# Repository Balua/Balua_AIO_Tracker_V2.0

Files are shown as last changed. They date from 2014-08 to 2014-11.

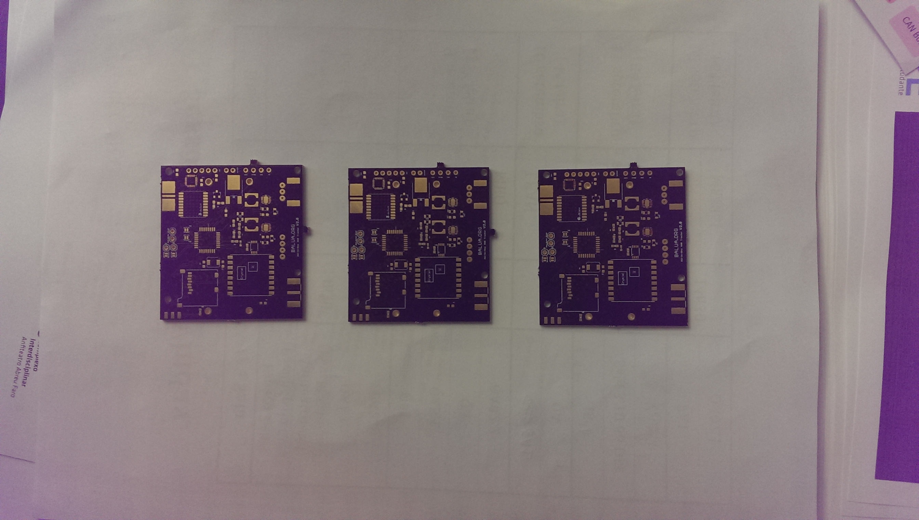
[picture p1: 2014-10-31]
PCB.jpg

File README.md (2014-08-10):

### Balua_AIO_Tracker_V2.0 - Board finished for printing, schematic and layout completed but still to be tested...

#### Updated version of the original tracker found in the Balua_AIO_Tracker_V1.0 repository with extra features and small corrections

#### Features:

#####Microprocessor
- ATMEGA 328p smd package

#####Power
- Step up Boost Converters from 2 AA Batteries to 3.3V and 5V

#####Communication
- Radiometrix HX1 - VHF Narrow Band FM High Power (300mW) Transmitter with SMA Antenna
- RFM22B ISM Transceiver Module with SMA Antenna

#####GPS
- Ublox Max 7 GPS with Quad V GPS antenna with jumpers in the RX/TX line and in the I2C for hardware selectable communication mode (NEW!!!)

#####Sensors
- SMD Onewire temperature sensor - DS18B20
- Battery Voltage sensing
- 0-15psi Pressure Sensor SMT mount - HSCSANN015PA2A3
- 9-axis Motion Tracking MEMS (3-axis gyroscope, 3-axis accelerometer and magnetometer) - MPU-9150 (NEW!!!)

#####Storage
- MicroSD Socket

#####Programming
- SMD AVR SPI Programming pins available (NEW!!!)

#####External pins
- I2c Pins with pull-up for expansion available
- 2 pins for Software Serial
- 2 pins for Hardware Serial
- Power Pins for external power (VBatt, 5V, 3.3V and GND) (NEW!!!)
- Power pins for Cutoff system (NEW!!!)

#####Other
- On Board AA battery holder
- 5V boost converter with enable controllable
- UBlox GPS Power ON Controllable
- RFM22B Radio enable pin Controllable
- On board LED
- Cutoff System implemented (NEW!!!)

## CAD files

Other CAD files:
AIO_tracker_V1.0-tcream.dxf
AIO_tracker_V1.0-bcream.dxf

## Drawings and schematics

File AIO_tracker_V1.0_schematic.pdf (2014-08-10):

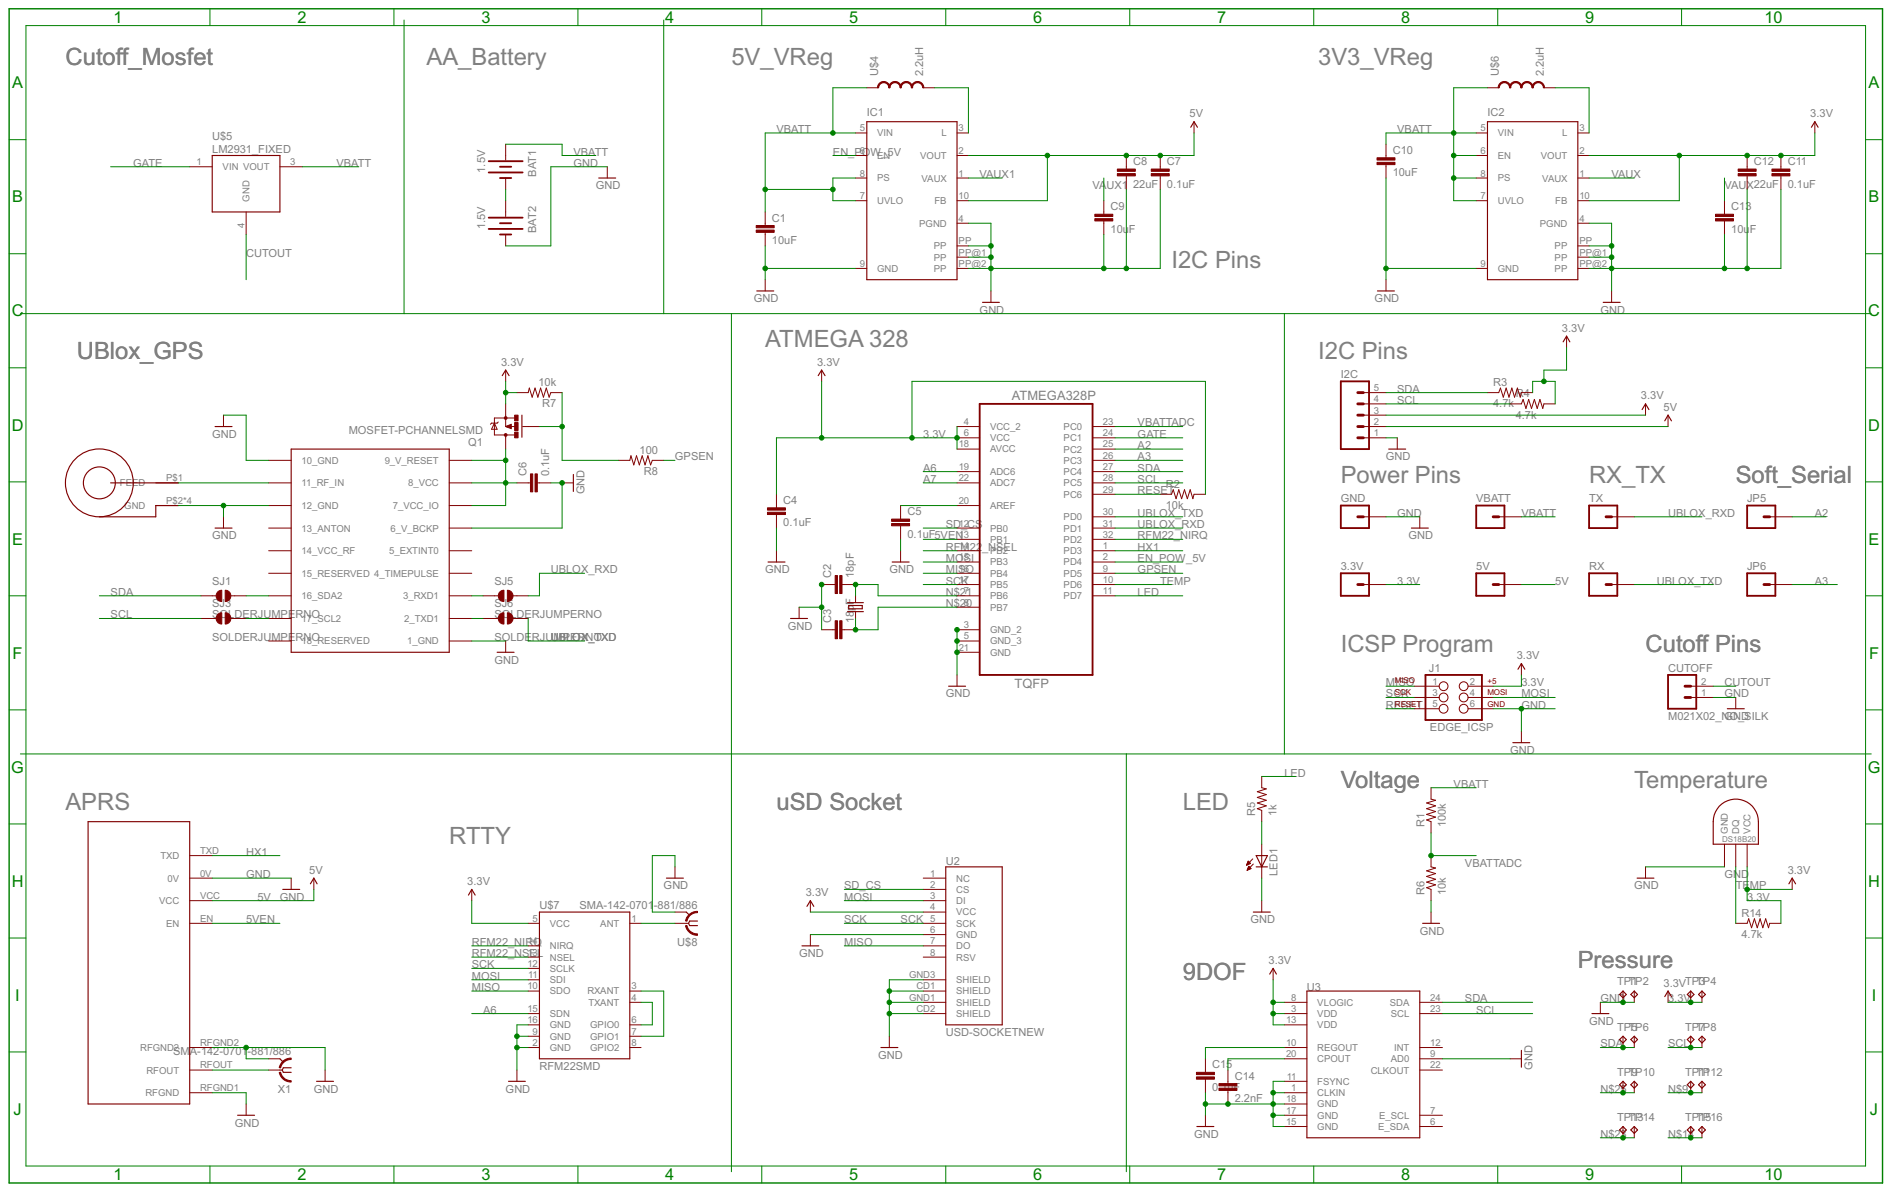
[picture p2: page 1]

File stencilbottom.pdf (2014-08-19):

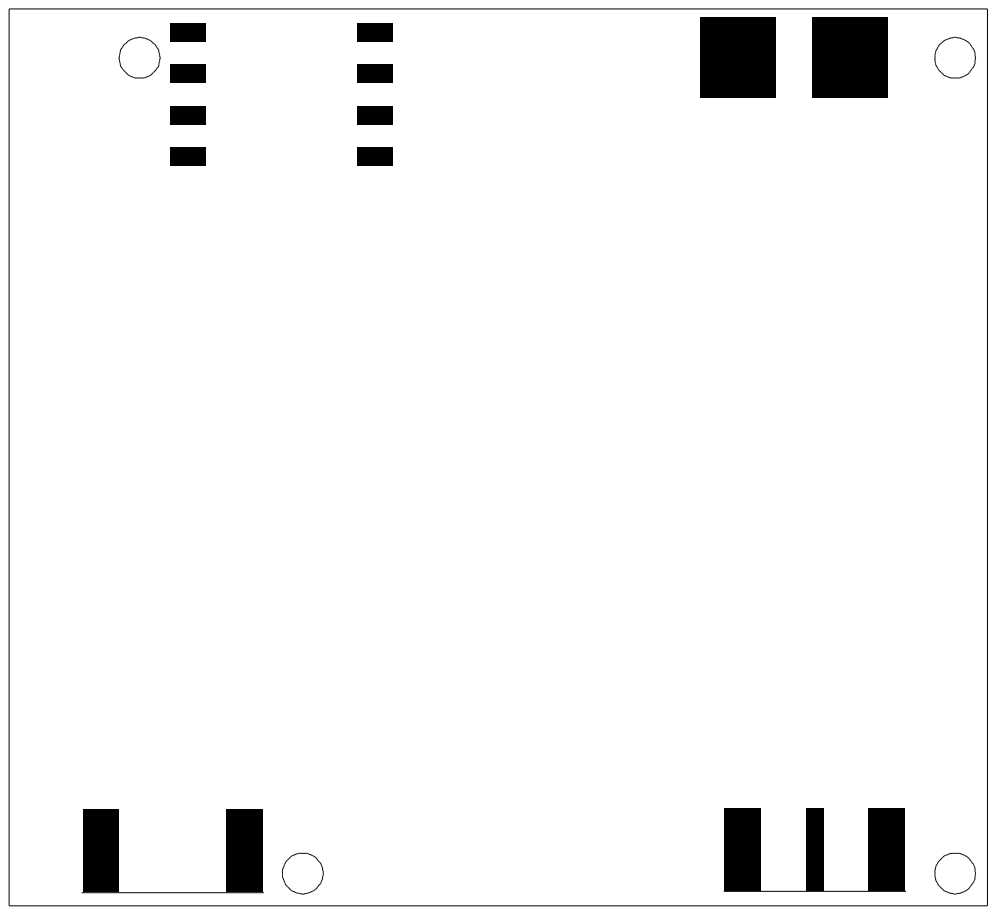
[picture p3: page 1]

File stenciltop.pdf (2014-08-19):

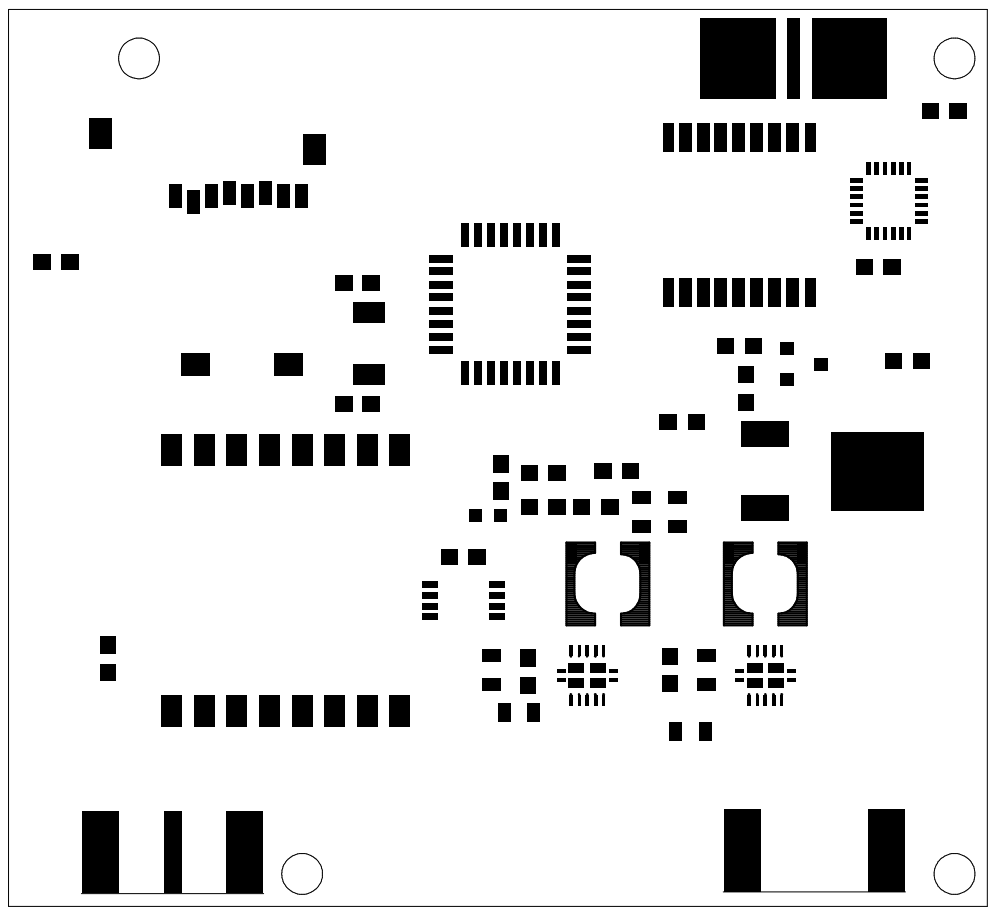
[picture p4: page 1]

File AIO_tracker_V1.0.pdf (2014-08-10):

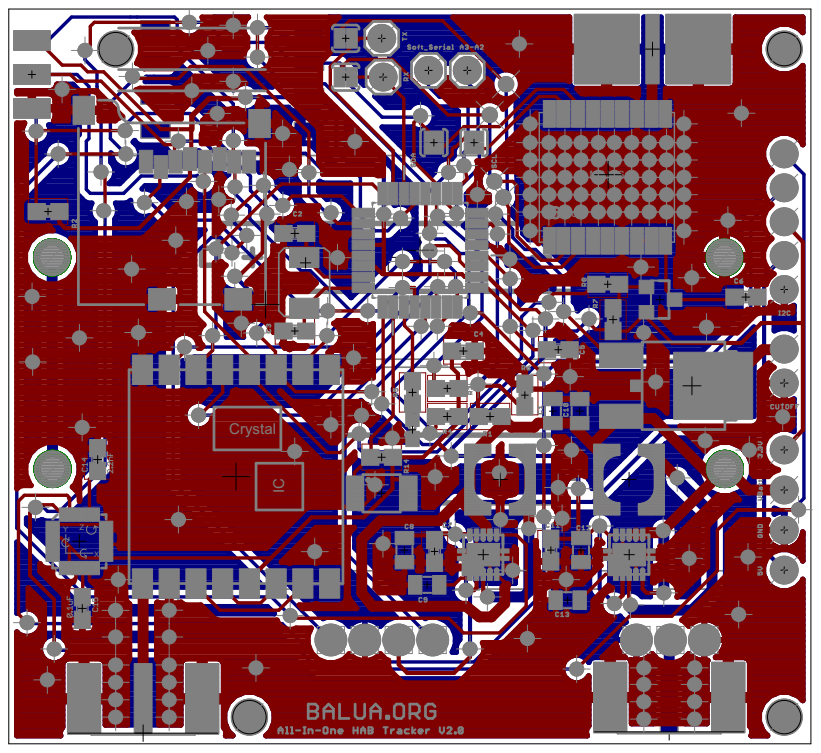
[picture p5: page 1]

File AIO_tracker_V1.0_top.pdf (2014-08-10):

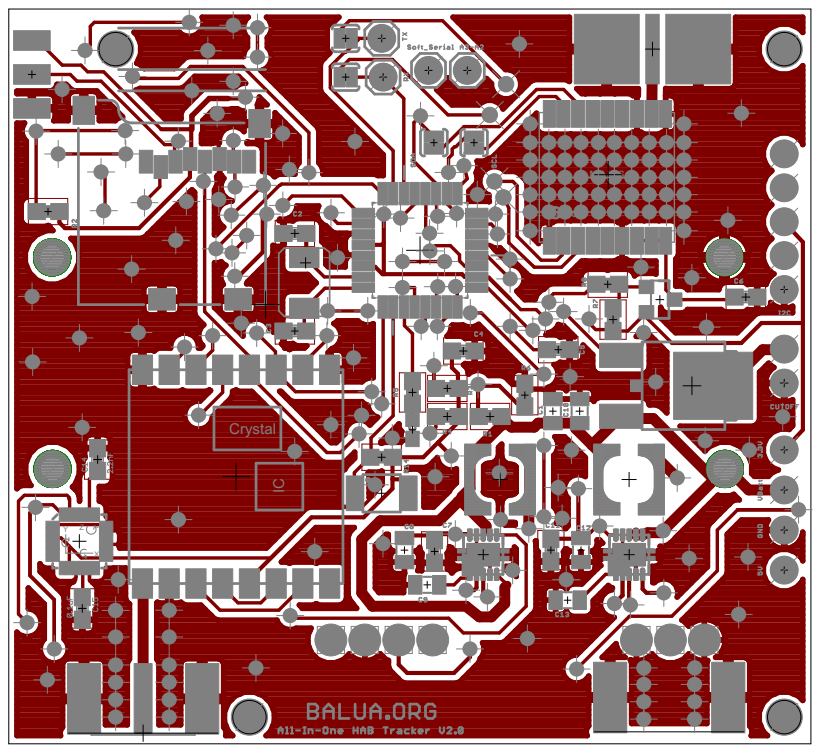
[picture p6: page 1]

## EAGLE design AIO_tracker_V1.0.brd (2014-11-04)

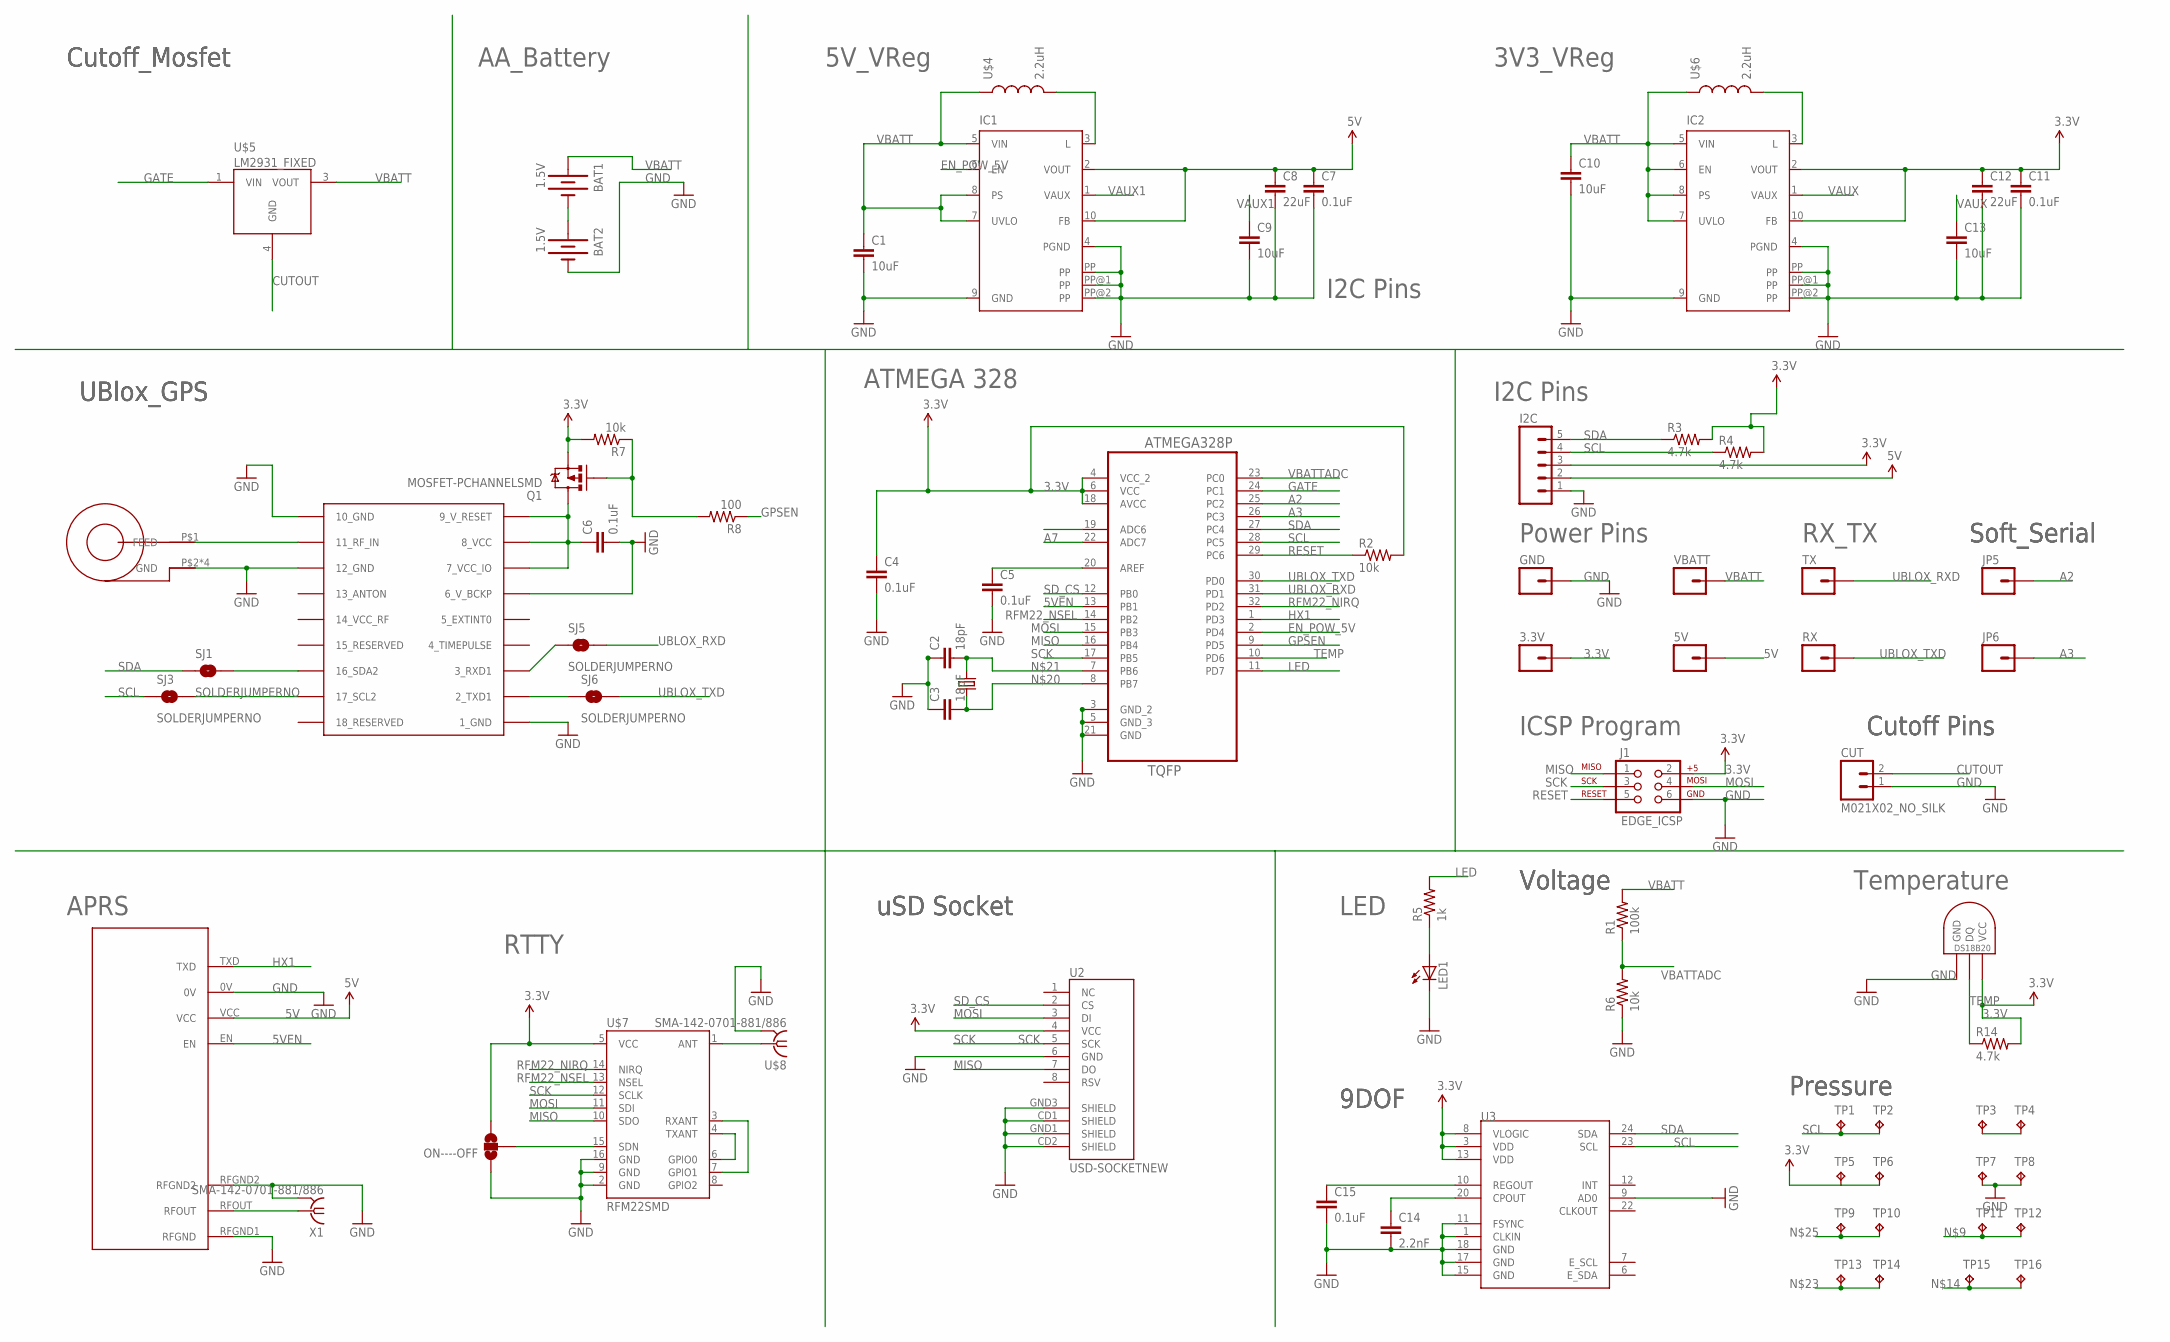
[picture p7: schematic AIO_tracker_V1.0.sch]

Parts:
3.3V, 5V: M01SMDNS; 1X01NS
BAT1, BAT2: 1.5V; BATTERY-AA-KIT
C1, C9, C10, C13: 10uF; 0805
C2, C3: 18pF; 0603-CAP
C4, C5, C6, C7, C11, C15: 0.1uF; 0603-CAP
C8, C12: 22uF; 0805
C14: 2.2nF; 0603-CAP
CUT: M021X02_NO_SILK; 1X02_NO_SILK
GND: M01SMDNS; 1X01NS
I2C: M05NO_SILK; 1X05_NO_SILK
IC1, IC2: TPS61201; S-PDSO-N10
J1: EDGE_ICSP; EDGE_MOUNTED_ICSP
JP5, JP6: M01PTH; 1X01
LED1: LED0603; LED-0603
ON----OFF: SOLDERJUMPER_2WAY-OLDT; SJ_2
Q1: MOSFET-PCHANNELSMD; SOT23-3
R1: 100k; 0603-RES
R2, R6, R7: 10k; 0603-RES
R3, R4, R14: 4.7k; 0603-RES
R5: 1k; 0603-RES
R8: 100; 0603-RES
RX: M01PTH; 1X01
SJ1, SJ3, SJ5, SJ6: SOLDERJUMPERNO; SJ_2S-NO
TP1, TP2, TP3, TP4, TP5, TP6, TP7, TP8, TP9, TP10, TP11, TP12, TP13, TP14, TP15, TP16: TPTP10SQ; TP10SQ
TX: M01PTH; 1X01
U1: ATMEGA328P-AU; QFP80P900X900X120-32N
U2: USD-SOCKETNEW; MICRO-SD-SOCKET-PP
U3: MPU-9150QFN-24-NP; QFN-24-NP
U$1: UBLOX_MAX
U$2: JDGA-REMQV-ANTENNA; JDGA-RIGID_COMBO_PAD
U$3: NTX2-VERTICAL
U$4, U$6: 2.2uH; COILCRAFT_MSS5131
U$5: LM2931_FIXED; DPAK
U$7: RFM22SMD; RFM22-XXX-S2
U$8: SMA-142-0701-881/886; J502-ND-142-0701-881/886
U$9: DS1820; µSOP8
VBATT: M01SMDNS; 1X01NS
X1: SMA-142-0701-881/886; J502-ND-142-0701-881/886
Y1: ABRACON_ABM3_CRYSTAL

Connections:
3.3V: 3.3V.1, C4.1, C11.1, C12.1, I2C.3, IC2.2 (VOUT), IC2.10 (FB), J1.2, ON----OFF.3, Q1.2 (S), R2.2, R3.2, R4.2, R7.2, R14.2, TP5.TP, TP6.TP, U1.4 (VCC_2), U1.6 (VCC), U1.18 (AVCC), U2.4 (VCC), U3.3 (VDD), U3.8 (VLOGIC), U3.13 (VDD), U$7.5 (VCC), U$9.8 (VCC)
5V: 5V.1, C7.1, C8.1, I2C.2, IC1.2 (VOUT), IC1.10 (FB), U$3.VCC
5VEN: U1.13 (PB1), U$3.EN
A2: JP5.1, U1.25 (PC2)
A3: JP6.1, U1.26 (PC3)
A7: U1.22 (ADC7)
CUTOUT: CUT.2, U$5.4 (GND)
EN_POW_5V: IC1.6 (EN), U1.2 (PD4)
GATE: U1.24 (PC1), U$5.1 (VIN)
GND: BAT2.GND@1 (-), C1.2, C2.1, C3.1, C4.2, C5.2, C6.2, C7.2, C8.2, C9.2, C10.2, C11.2, C12.2, C13.2, C14.2, C15.2, CUT.1, GND.1, I2C.1, IC1.4 (PGND), IC1.9 (GND), IC1.PP, IC1.PP@1 (PP), IC1.PP@2 (PP), IC2.4 (PGND), IC2.9 (GND), IC2.PP, IC2.PP@1 (PP), IC2.PP@2 (PP), J1.6, LED1.C, ON----OFF.1, R6.1, TP7.TP, TP8.TP, U1.3 (GND_2), U1.5 (GND_3), U1.21 (GND), U2.6 (GND), U2.CD1 (SHIELD), U2.CD2 (SHIELD), U2.GND1 (SHIELD), U2.GND3 (SHIELD), U3.1 (CLKIN), U3.9 (AD0), U3.11 (FSYNC), U3.15 (GND), U3.17 (GND), U3.18 (GND), U$1.1_GND, U$1.6_V_BCKP, U$1.10_GND, U$1.12_GND, U$2.P$2 (GND), U$2.P$3 (GND), U$2.P$4 (GND), U$2.P$5 (GND), U$3.0V, U$3.RFGND1 (RFGND), U$3.RFGND2, U$7.2 (GND), U$7.9 (GND), U$7.16 (GND), U$8.G@1 (2), U$8.G@2 (2), U$8.G@3 (2), U$8.G@4 (2), U$9.4 (GND), X1.G@1 (2), X1.G@2 (2), X1.G@3 (2), X1.G@4 (2)
GPSEN: R8.1, U1.9 (PD5)
HX1: U1.1 (PD3), U$3.TXD
LED: R5.2, U1.11 (PD7)
MISO: J1.1, U1.16 (PB4), U2.7 (DO), U$7.10 (SDO)
MOSI: J1.4, U1.15 (PB3), U2.3 (DI), U$7.11 (SDI)
unnamed: LED1.A, R5.1
unnamed: Q1.1 (G), R7.1, R8.2
unnamed: U$1.11_RF_IN, U$2.P$1 (FEED)
unnamed: C5.1, U1.20 (AREF)
unnamed: U$3.RFOUT, X1.1
unnamed: C6.1, Q1.3 (D), U$1.7_VCC_IO, U$1.8_VCC, U$1.9_V_RESET
unnamed: IC1.3 (L), U$4.P$1 (2)
unnamed: TP11.TP, TP12.TP
unnamed: BAT1.GND@1 (-), BAT2.PWR@1 (+)
unnamed: SJ5.1, U$1.3_RXD1
unnamed: SJ6.1, U$1.2_TXD1
unnamed: U$7.1 (ANT), U$8.1
unnamed: TP15.TP, TP16.TP
unnamed: SJ1.2, U$1.16_SDA2
unnamed: SJ3.2, U$1.17_SCL2
unnamed: C15.1, U3.10 (REGOUT)
unnamed: C14.1, U3.20 (CPOUT)
unnamed: IC2.3 (L), U$6.P$1 (2)
unnamed: C3.2, U1.8 (PB7), Y1.P$1 (1)
unnamed: C2.2, U1.7 (PB6), Y1.P$2 (2)
unnamed: TP13.TP, TP14.TP
unnamed: TP9.TP, TP10.TP
unnamed: ON----OFF.2, U$7.15 (SDN)
unnamed: U$7.3 (RXANT), U$7.7 (GPIO1)
unnamed: U$7.4 (TXANT), U$7.6 (GPIO0)
RESET: J1.5, R2.1, U1.29 (PC6)
RFM22_NIRQ: U1.32 (PD2), U$7.14 (NIRQ)
RFM22_NSEL: U1.14 (PB2), U$7.13 (NSEL)
SCK: J1.3, U1.17 (PB5), U2.5 (SCK), U$7.12 (SCLK)
SCL: I2C.4, R4.1, SJ3.1, TP1.TP, TP2.TP, U1.28 (PC5), U3.23 (SCL)
SDA: I2C.5, R3.1, SJ1.1, TP3.TP, TP4.TP, U1.27 (PC4), U3.24 (SDA)
SD_CS: U1.12 (PB0), U2.2 (CS)
TEMP: R14.1, U1.10 (PD6), U$9.1 (DQ)
UBLOX_RXD: SJ5.2, TX.1, U1.31 (PD1)
UBLOX_TXD: RX.1, SJ6.2, U1.30 (PD0)
VAUX: C13.1, IC2.1 (VAUX)
VAUX1: C9.1, IC1.1 (VAUX)
VBATT: BAT1.PWR@1 (+), C1.1, C10.1, IC1.5 (VIN), IC1.7 (UVLO), IC1.8 (PS), IC2.5 (VIN), IC2.6 (EN), IC2.7 (UVLO), IC2.8 (PS), R1.2, U$4.P$2 (1), U$5.3 (VOUT), U$6.P$2 (1), VBATT.1
VBATTADC: R1.1, R6.2, U1.23 (PC0)

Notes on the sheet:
I2C Pins
Soft_Serial
RX_TX
Power Pins
ICSP Program
Cutoff Pins
5V_VReg
3V3_VReg
AA_Battery
Cutoff_Mosfet
UBlox_GPS
ATMEGA 328
uSD Socket
APRS
RTTY
LED
Voltage
9DOF
Pressure
Temperature

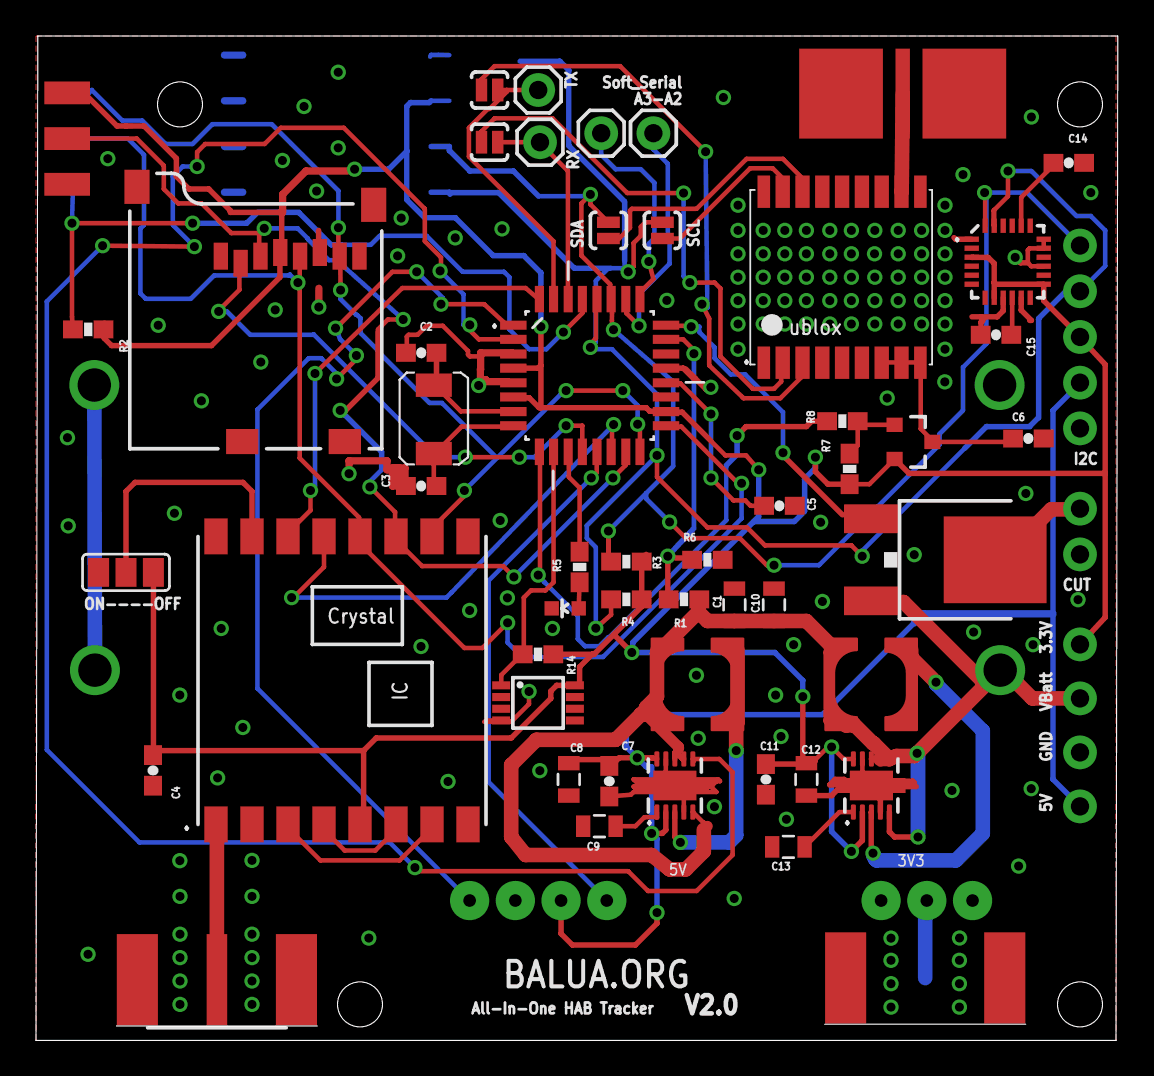
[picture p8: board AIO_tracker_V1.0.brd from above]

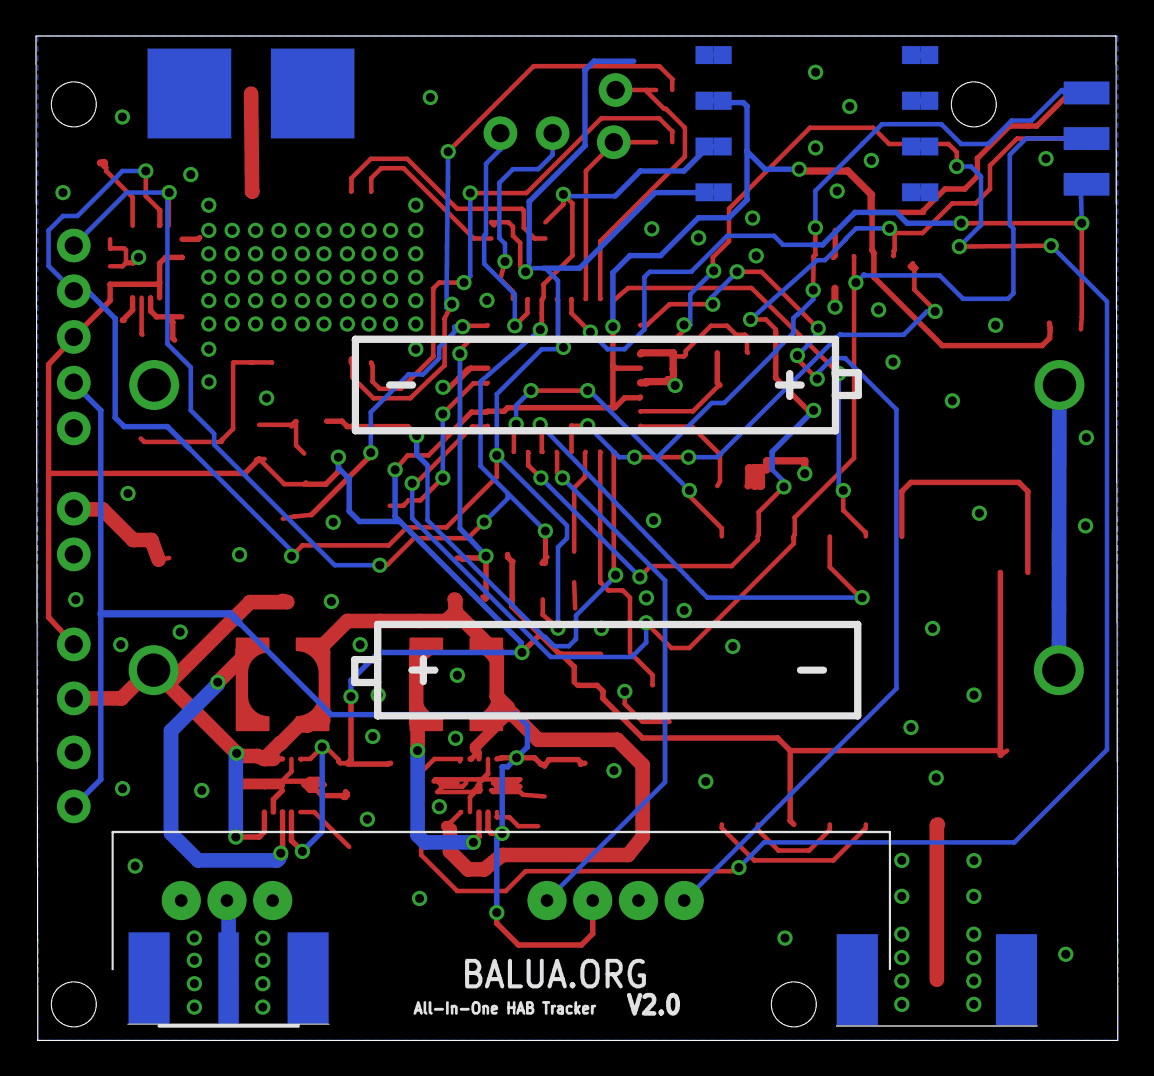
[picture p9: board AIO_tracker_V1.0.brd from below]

Board: 2 copper layers, 60.1 x 55.8 mm, 76 parts (20 on the bottom side), 53 nets.

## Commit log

2014-06-30 First Commit
    Main features implemented. Schematic and layout complete with minor
    changes that will be corrected in later commits
    [AIO_tracker_V1.0.brd, AIO_tracker_V1.0.sch]
2014-06-30 Replaced tx pin of HX1 from PD4 to PD3
    Replaced tx pin of HX1 from PD4 to PD3 in atmega 328 and 5V enable from
    PD3 to PD4 due to the fact that the PD3 pin is a PWM pin
2014-06-30 Replaced 0306 smd caps with 0805 smd caps
    Replaced the package of the 0306 smd caps with 0805 smd caps of the
    larger capacitors (>10uF)
    [AIO_tracker_V1.0.brd]
2014-06-30 Replaced HX1 Enable, added Soft Serial (A3 and A2)
    Replaced HX1 Enable with a non pwm pin, added soft serial (A2 and A3)
    silkscreened isolated pins.
    [AIO_tracker_V1.0.brd, AIO_tracker_V1.0.sch]
2014-06-30 Added extra power pins (5V, 3.3V and GND) and more
    Added extra power pins (5V, 3.3V and GND)
    Added I2C to Ublox
    Placed smd jumpers in both I2C and RX/TX of Ublox for hardware selection
    of communication mode.
    Added pins for external RX/TX communication with arduino.
    PCB layout updated
    [AIO_tracker_V1.0.brd, AIO_tracker_V1.0.sch]
2014-07-01 tirei o ponto final
    so para testar
2014-07-18 Updated library and erros
    - Ava library updated
    - SDN pin of the RFM22b connected to A6 instead of always HIGH
    - Updated Sarantel Antenna Footprint
    - A7 to external pin
    [AIO_tracker_V1.0.brd]
2014-07-28 Added NTX2 Support option
    Added NTX2 Support option and finished routing
    [AIO_tracker_V1.0.brd, AIO_tracker_V1.0.sch]
2014-07-28 corrected a few erros with the NTX2
    Added back pads to the HX1 footprint, corrected the voltage divider,
    corrected the antenna layout, changed SDN of RFM22b to the A7, corrected
    the values in the schematic
    Missing:
    - Cuttof system
    - New pressure sensor
    [AIO_tracker_V1.0.brd, AIO_tracker_V1.0.sch]
2014-07-29 changed holes to match the stencil
    changed holes to match the stencil sticks (2.5mm) and the 10mm spacing
    between them
    [AIO_tracker_V1.0.brd]
2014-08-04 removed jumpers and ntx2 support
    removed jumpers and ntx2 support
    [AIO_tracker_V1.0.brd, AIO_tracker_V1.0.sch]
2014-08-05 added 9dof, new antena, new crystal, cutoff...
    added 9dof, new antena, new crystal, cutoff system and changed layout
    [AIO_tracker_V1.0.brd, AIO_tracker_V1.0.sch]
2014-08-10 Final without logo
    [AIO_tracker_V1.0 - Copy (2).brd, AIO_tracker_V1.0 - Copy (2).sch, AIO_tracker_V1.0 - Copy.brd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]
2014-08-10 corrected pcb errors for oshpark
    [AIO_tracker_V1.0.brd, AIO_tracker_V1.0.sch, DRILEGEND.CFG]
2014-08-10 corrected last things
    [AIO_tracker_V1.0.brd, AIO_tracker_V1.0.sch]
2014-08-10 Small .sch changes
    [AIO_tracker_V1.0.sch]
2014-08-10 final commit of pcb (fingers crossed)
    [AIO_tracker_V1.0.brd]
2014-08-11 Several thing corrected (still....=/)
    Position of 9DOF, tended vias, names, etc
    [AIO_tracker_V1.0.brd, AIO_tracker_V1.0.sch]
2014-08-11 last one seriously
    [AIO_tracker_V1.0.brd]
2014-08-19 Added stencil top and bottom
    Added stencil top and bottom
    [AIO_tracker_V1.0.brd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]
2014-09-19 added dxf stencil top and bottom
    [AIO_tracker_V1.0-bcream.dxf, AIO_tracker_V1.0-tcream.dxf]
2014-10-31 fixed some details after receiving the printed pcb
    - Fixed size of silkscreen
    - Added pin 1 points in silkscreen
    - Removed A6 and replaced the SDN of RFM22 with a 3way jumper
    Still need to be fixed
    - Pressure sensor size in pcb
    - Buy the correct SMA Jacks (
    http://pt.mouser.com/ProductDetail/Johnson-Cinch-Connectivity-Solutions/142-0701-881/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)
    [AIO_tracker_V1.0-tcream.dxf, AIO_tracker_V1.0.brd, AIO_tracker_V1.0.sch]
2014-10-31 added image of the PCB received from oshpark
2014-11-04 last changes post fabrication
    - changed position of the pressure sensor pins (reversed)
    - Added more spacing from the AA battery holders
    [AIO_tracker_V1.0.brd, AIO_tracker_V1.0.sch]

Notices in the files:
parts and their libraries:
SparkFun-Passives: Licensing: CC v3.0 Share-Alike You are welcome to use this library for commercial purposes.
